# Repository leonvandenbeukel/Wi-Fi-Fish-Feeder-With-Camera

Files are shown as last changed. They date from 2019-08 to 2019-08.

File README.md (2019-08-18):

# Wi-Fi Fish Feeder With Camera

### Components

You need the following components:

* An ESP32-Cam module with Wi-Fi Antenna
* A large continuous rotating servo (it might also work with the more popular tiny MG90 but then you would have to modify it for continuous rotation and design another servo mount)
* Micro usb pcb
* 5V power adapter
* A regular 608 bearing 
* M3 nuts, bolts and washers
* 15 * 15 mm aluminium rod (optional)
* Wires

### 3D Printing

Use these settings: 0.2 / 10% infill. Support is needed for some pieces.

### Schema

Connect 5V, GND and GPIO12 for the signal wire to the servo. Use a micro usb pcb to connect it to a regular 5V power adapter.

### Arduino source

First install the ESP32 library. 
1. Start the Arduino IDE
2. Go to File > Preferences
3. Edit the "Additional Board Manager URLs" and add this URL:
    https://dl.espressif.com/dl/package_esp32_index.json
4. Go to Tools > Board > Boards Manager
5. Search for ESP32 and Install

Use an FTDI board and connect RX of the FTDI board to TX of the ESP32 board, TX (FTDI) to RX (ESP32) together with GND and 3.3V. If you're having trouble with the ESP32 (horizontal lines on the camera or "brownout detected" errors, you can try connecting an external 5V power supply to the 5V pin of the ESP32 (and connect GND's).  

Open the "WiFi-Fish-Feeder-With-Camera.ino" file from this repository and change the following setttings:

* Tools > Board, select ESP32 Wrover Module
* Tools > Port, select the COM port 
* In Tools > Partition Scheme, select "Huge APP (3MB No OTA)"

To upload the code, connect GPIO0 to GND and press the reset button on the device. Then hit upload in the Arduino IDE. After succesfully uploading press the reset button again and check the serial monitor to find out which IP Address it get's assigned. Browse to that IP and check if everything works.

### YouTube video

<a href="https://youtu.be/dWhmNZHbLFU" target="_blank">Click to view: Fish Feeder</a>

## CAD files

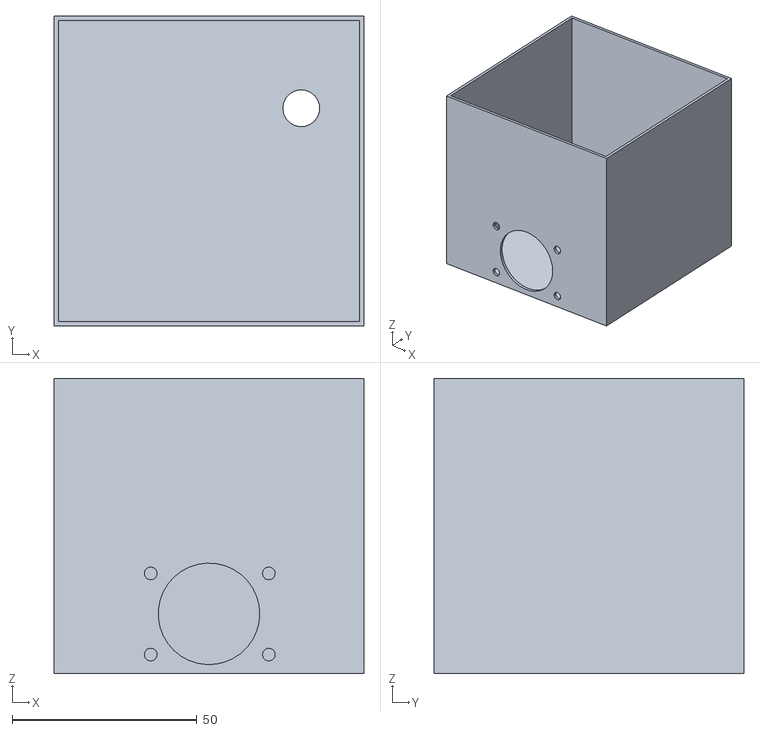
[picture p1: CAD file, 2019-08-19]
STL/Box.stl
84.0 x 84.0 x 80.0

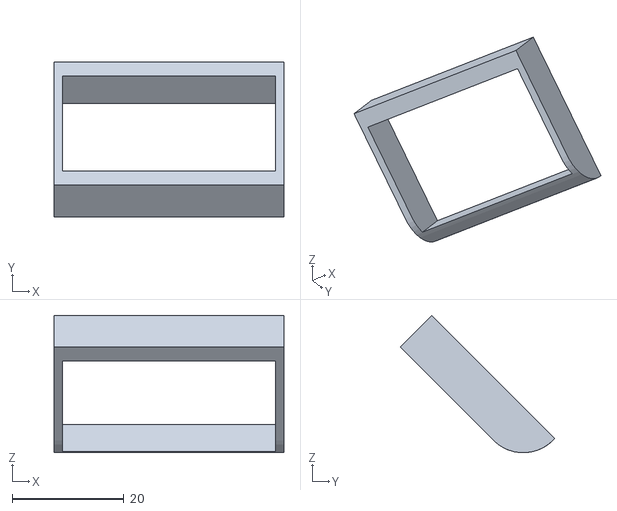
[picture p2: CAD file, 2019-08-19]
STL/Camera standoff.stl
41.1 x 27.6 x 24.5

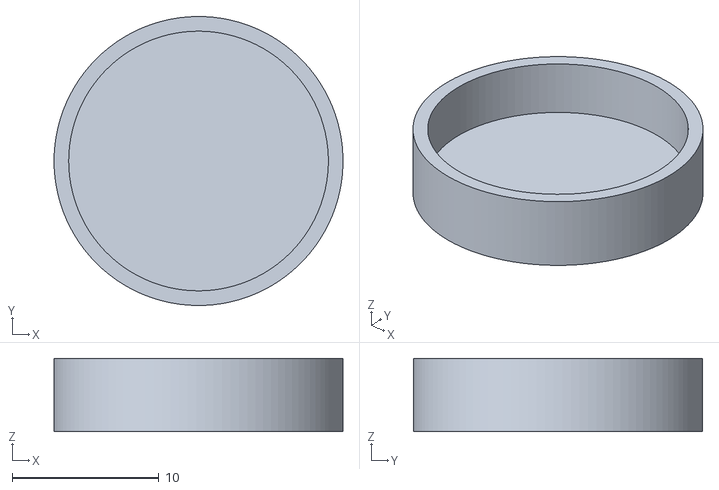
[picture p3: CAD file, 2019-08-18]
STL/Cap to close it off.stl
19.7 x 19.7 x 5.00

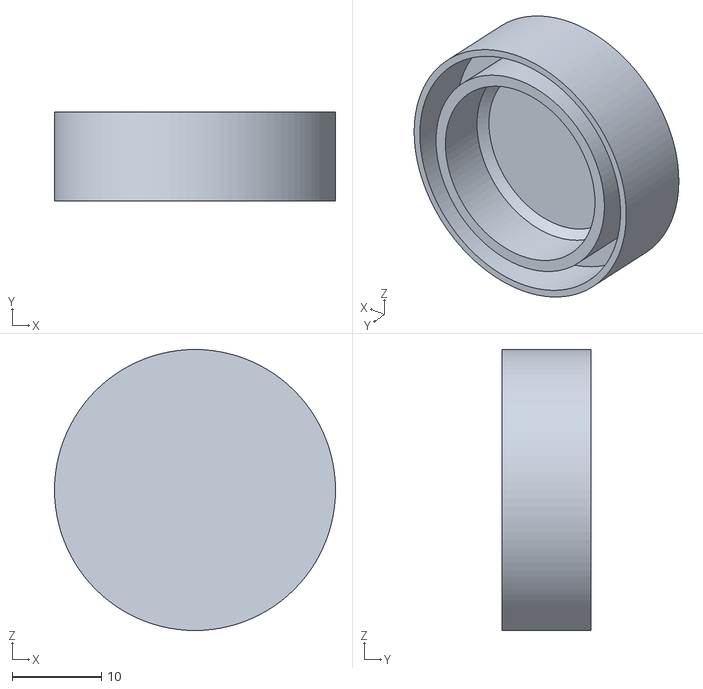
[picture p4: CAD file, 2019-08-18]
STL/Bearing Cap.stl
31.5 x 10.0 x 31.5

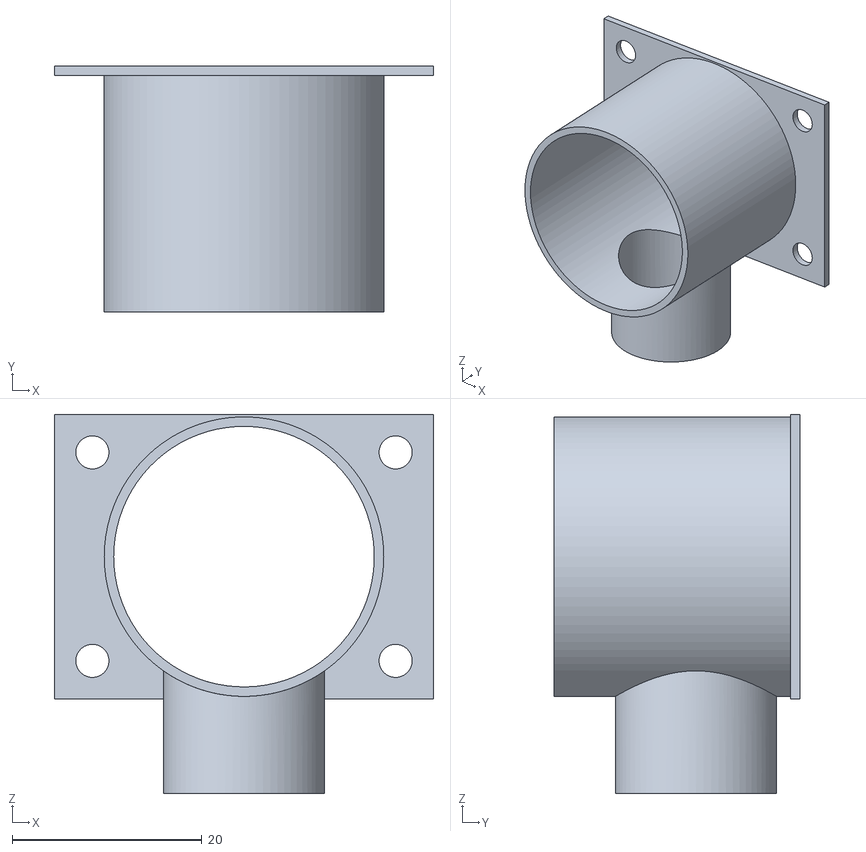
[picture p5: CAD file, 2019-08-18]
STL/Outlet.stl
40.0 x 26.0 x 40.0

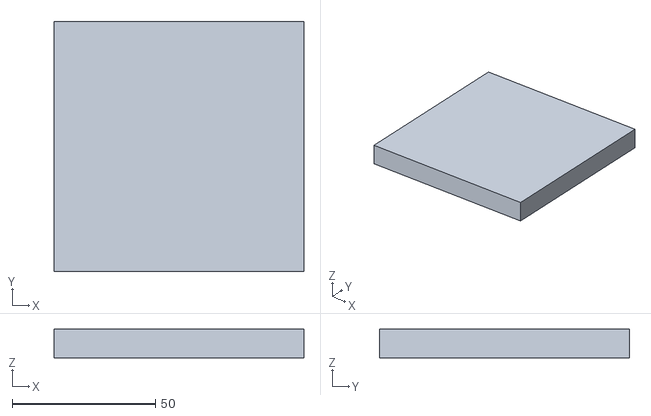
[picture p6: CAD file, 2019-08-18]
STL/Box lid.stl
87.2 x 87.2 x 10.0

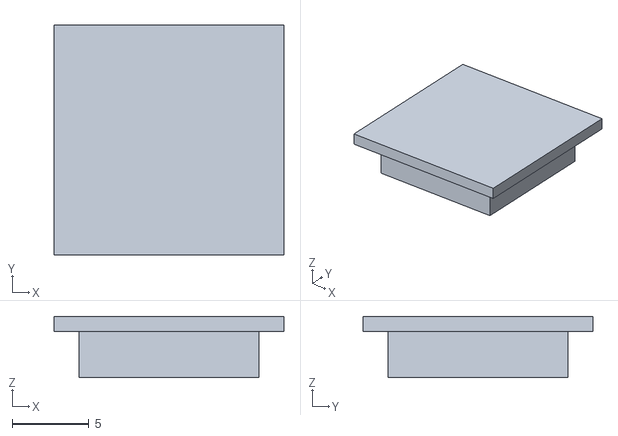
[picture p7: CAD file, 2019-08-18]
STL/End Cap.stl
15.0 x 15.0 x 4.00

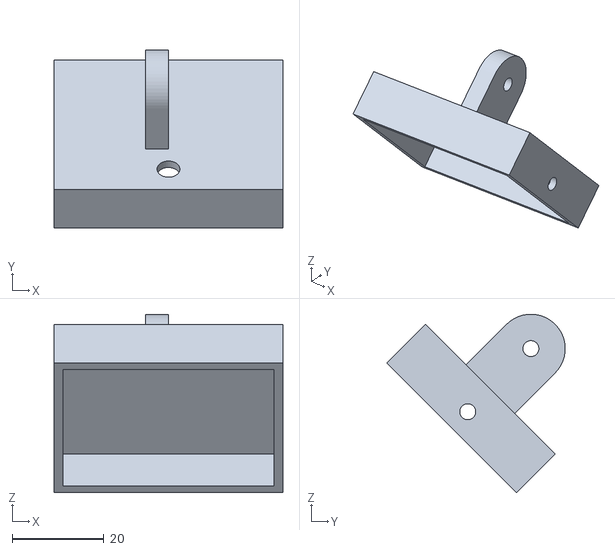
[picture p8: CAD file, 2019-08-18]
STL/Camera back tilt.stl
50.0 x 39.0 x 39.0

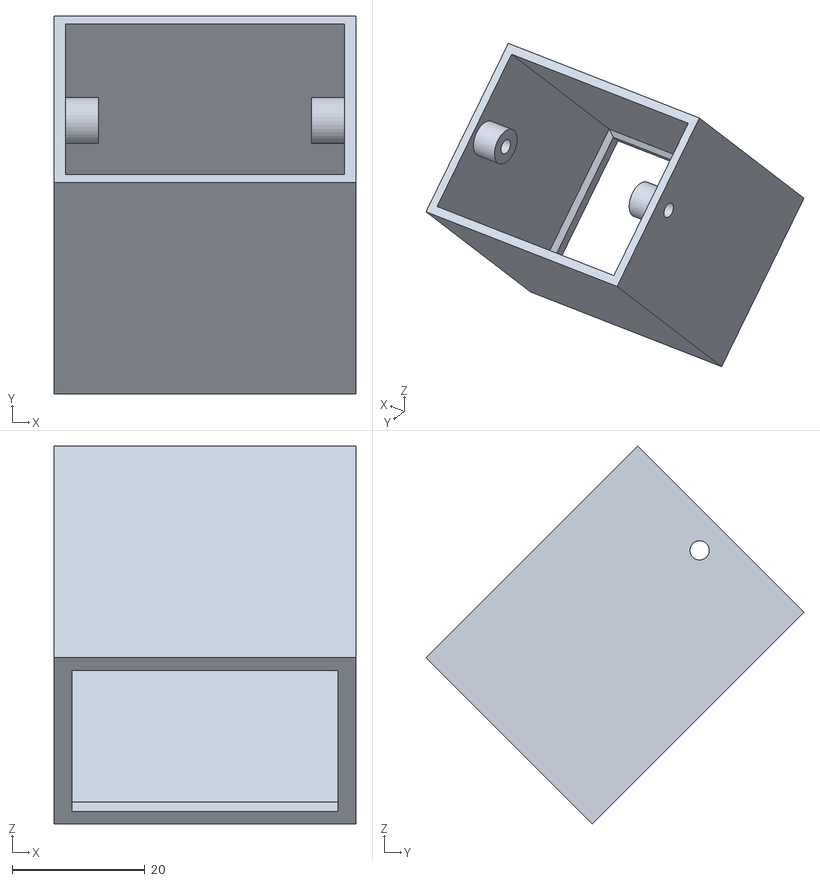
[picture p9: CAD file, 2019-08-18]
STL/Camera body.stl
45.4 x 56.9 x 56.9

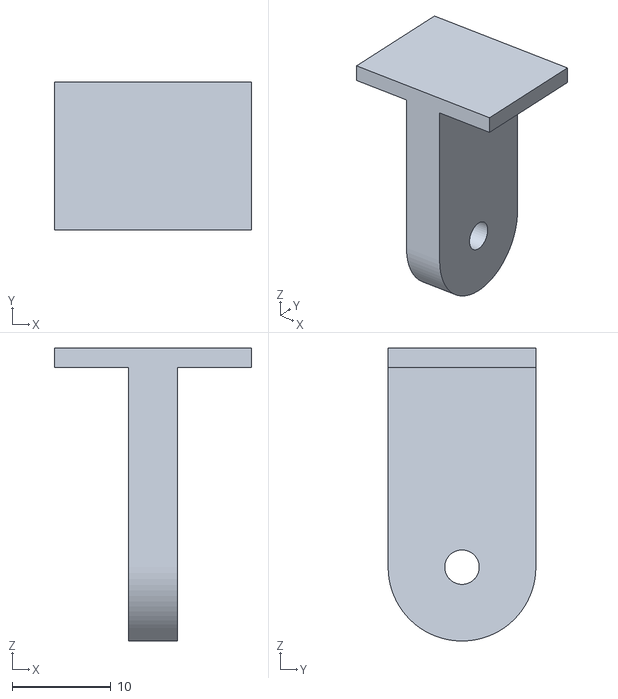
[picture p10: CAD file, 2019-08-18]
STL/Camera joint.stl
20.0 x 15.0 x 29.7

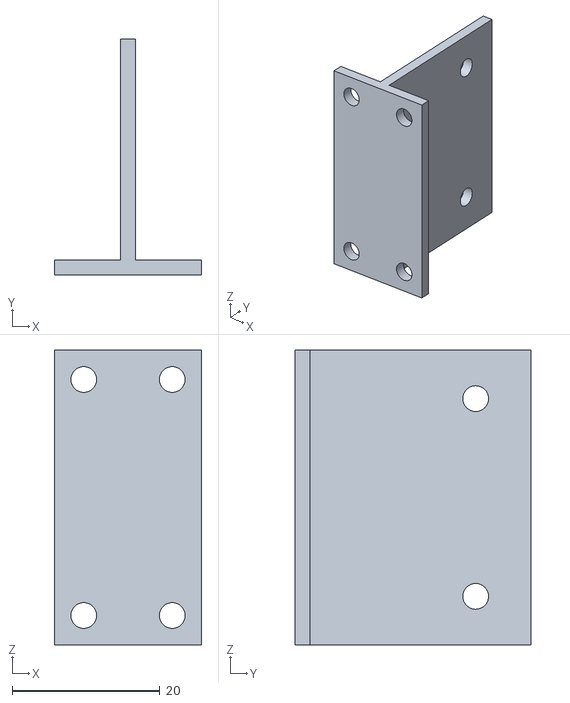
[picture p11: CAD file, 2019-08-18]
STL/Connection.stl
20.0 x 32.0 x 40.0

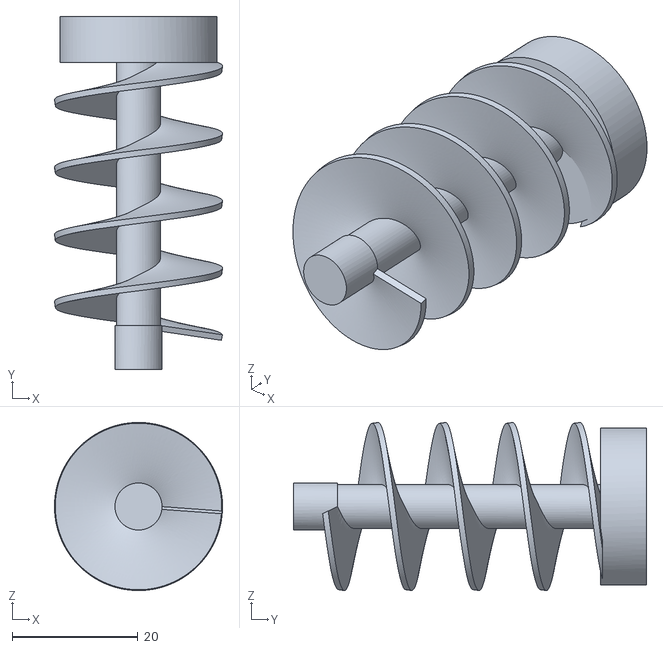
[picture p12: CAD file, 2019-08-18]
STL/Auger.stl
26.8 x 56.2 x 26.8

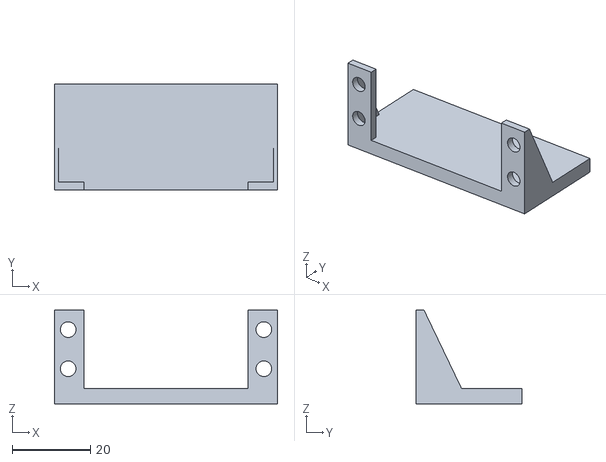
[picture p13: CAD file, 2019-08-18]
STL/Servo Mount.stl
57.0 x 27.0 x 24.0

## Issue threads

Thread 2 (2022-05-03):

Missing files

rlxd, 2022-05-03:
Arduino:1.8.20 Hourly Build 2022/04/25 09:33 (Windows 10), Board:"ESP32 Wrover Module, Huge APP (3MB No OTA/1MB SPIFFS), QIO, 40MHz, 115200, None"

Meerdere bibliotheken gevonden voor "WiFi.h"

app_httpd.cpp:36:20: fatal error: dl_lib.h: No such file or directory

Gebruikt: C:\Users\roy19\AppData\Local\Arduino15\packages\esp32\hardware\esp32\1.0.6\libraries\WiFi

compilation terminated.

Niet gebruikt: C:\Users\roy19\Desktop\arduino-nightly\libraries\WiFi

exit status 1

dl_lib.h: No such file or directory

Dit rapport zou meer informatie bevatten met
"Uitgebreide uitvoer weergeven tijden compilatie"
optie aan in Bestand -> Voorkeuren.

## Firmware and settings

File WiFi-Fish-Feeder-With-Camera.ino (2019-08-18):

#include "esp_camera.h"
#include <WiFi.h>

// Board: ESP32 Wrover
// Partition scheme: Huge APP

// Select camera model
//#define CAMERA_MODEL_WROVER_KIT
//#define CAMERA_MODEL_ESP_EYE
//#define CAMERA_MODEL_M5STACK_PSRAM
//#define CAMERA_MODEL_M5STACK_WIDE
#define CAMERA_MODEL_AI_THINKER

#include "camera_pins.h"

const char* ssid = "*** your ssid here ***";
const char* password = "*** your wi-fi password here ***";

void startCameraServer();
void checkFeederTimer();

void setup() {
  
  Serial.begin(115200);
  Serial.setDebugOutput(true);
  Serial.println();

  camera_config_t config;
  config.ledc_channel = LEDC_CHANNEL_0;
  config.ledc_timer = LEDC_TIMER_0;
  config.pin_d0 = Y2_GPIO_NUM;
  config.pin_d1 = Y3_GPIO_NUM;
  config.pin_d2 = Y4_GPIO_NUM;
  config.pin_d3 = Y5_GPIO_NUM;
  config.pin_d4 = Y6_GPIO_NUM;
  config.pin_d5 = Y7_GPIO_NUM;
  config.pin_d6 = Y8_GPIO_NUM;
  config.pin_d7 = Y9_GPIO_NUM;
  config.pin_xclk = XCLK_GPIO_NUM;
  config.pin_pclk = PCLK_GPIO_NUM;
  config.pin_vsync = VSYNC_GPIO_NUM;
  config.pin_href = HREF_GPIO_NUM;
  config.pin_sscb_sda = SIOD_GPIO_NUM;
  config.pin_sscb_scl = SIOC_GPIO_NUM;
  config.pin_pwdn = PWDN_GPIO_NUM;
  config.pin_reset = RESET_GPIO_NUM;
  config.xclk_freq_hz = 20000000;
  config.pixel_format = PIXFORMAT_JPEG;
  //init with high specs to pre-allocate larger buffers
  if(psramFound()){
    config.frame_size = FRAMESIZE_UXGA;
    config.jpeg_quality = 10;
    config.fb_count = 2;
  } else {
    config.frame_size = FRAMESIZE_SVGA;
    config.jpeg_quality = 12;
    config.fb_count = 1;
  }

#if defined(CAMERA_MODEL_ESP_EYE)
  pinMode(13, INPUT_PULLUP);
  pinMode(14, INPUT_PULLUP);
#endif

  // camera init
  esp_err_t err = esp_camera_init(&config);
  if (err != ESP_OK) {
    Serial.printf("Camera init failed with error 0x%x", err);
    return;
  }

  sensor_t * s = esp_camera_sensor_get();
  //initial sensors are flipped vertically and colors are a bit saturated
  if (s->id.PID == OV3660_PID) {
    s->set_vflip(s, 1);//flip it back
    s->set_brightness(s, 1);//up the blightness just a bit
    s->set_saturation(s, -2);//lower the saturation
  }
  //drop down frame size for higher initial frame rate
  s->set_framesize(s, FRAMESIZE_QVGA);

#if defined(CAMERA_MODEL_M5STACK_WIDE)
  s->set_vflip(s, 1);
  s->set_hmirror(s, 1);
#endif

  pinMode(4, OUTPUT);

  WiFi.begin(ssid, password);

  while (WiFi.status() != WL_CONNECTED) {
    delay(500);
    Serial.print(".");
  }
  Serial.println("");
  Serial.println("WiFi connected");

  startCameraServer();

  Serial.print("Camera Ready! Use 'http://");
  Serial.print(WiFi.localIP());
  Serial.println("' to connect");
}

void loop() {

   checkFeederTimer();
   delay(10);

}

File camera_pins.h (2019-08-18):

  
#if defined(CAMERA_MODEL_WROVER_KIT)
#define PWDN_GPIO_NUM    -1
#define RESET_GPIO_NUM   -1
#define XCLK_GPIO_NUM    21
#define SIOD_GPIO_NUM    26
#define SIOC_GPIO_NUM    27

#define Y9_GPIO_NUM      35
#define Y8_GPIO_NUM      34
#define Y7_GPIO_NUM      39
#define Y6_GPIO_NUM      36
#define Y5_GPIO_NUM      19
#define Y4_GPIO_NUM      18
#define Y3_GPIO_NUM       5
#define Y2_GPIO_NUM       4
#define VSYNC_GPIO_NUM   25
#define HREF_GPIO_NUM    23
#define PCLK_GPIO_NUM    22

#elif defined(CAMERA_MODEL_ESP_EYE)
#define PWDN_GPIO_NUM    -1
#define RESET_GPIO_NUM   -1
#define XCLK_GPIO_NUM    4
#define SIOD_GPIO_NUM    18
#define SIOC_GPIO_NUM    23

#define Y9_GPIO_NUM      36
#define Y8_GPIO_NUM      37
#define Y7_GPIO_NUM      38
#define Y6_GPIO_NUM      39
#define Y5_GPIO_NUM      35
#define Y4_GPIO_NUM      14
#define Y3_GPIO_NUM      13
#define Y2_GPIO_NUM      34
#define VSYNC_GPIO_NUM   5
#define HREF_GPIO_NUM    27
#define PCLK_GPIO_NUM    25

#elif defined(CAMERA_MODEL_M5STACK_PSRAM)
#define PWDN_GPIO_NUM     -1
#define RESET_GPIO_NUM    15
#define XCLK_GPIO_NUM     27
#define SIOD_GPIO_NUM     25
#define SIOC_GPIO_NUM     23

#define Y9_GPIO_NUM       19
#define Y8_GPIO_NUM       36
#define Y7_GPIO_NUM       18
#define Y6_GPIO_NUM       39
#define Y5_GPIO_NUM        5
#define Y4_GPIO_NUM       34
#define Y3_GPIO_NUM       35
#define Y2_GPIO_NUM       32
#define VSYNC_GPIO_NUM    22
#define HREF_GPIO_NUM     26
#define PCLK_GPIO_NUM     21

#elif defined(CAMERA_MODEL_M5STACK_WIDE)
#define PWDN_GPIO_NUM     -1
#define RESET_GPIO_NUM    15
#define XCLK_GPIO_NUM     27
#define SIOD_GPIO_NUM     22
#define SIOC_GPIO_NUM     23

#define Y9_GPIO_NUM       19
#define Y8_GPIO_NUM       36
#define Y7_GPIO_NUM       18
#define Y6_GPIO_NUM       39
#define Y5_GPIO_NUM        5
#define Y4_GPIO_NUM       34
#define Y3_GPIO_NUM       35
#define Y2_GPIO_NUM       32
#define VSYNC_GPIO_NUM    25
#define HREF_GPIO_NUM     26
#define PCLK_GPIO_NUM     21

#elif defined(CAMERA_MODEL_AI_THINKER)
#define PWDN_GPIO_NUM     32
#define RESET_GPIO_NUM    -1
#define XCLK_GPIO_NUM      0
#define SIOD_GPIO_NUM     26
#define SIOC_GPIO_NUM     27

#define Y9_GPIO_NUM       35
#define Y8_GPIO_NUM       34
#define Y7_GPIO_NUM       39
#define Y6_GPIO_NUM       36
#define Y5_GPIO_NUM       21
#define Y4_GPIO_NUM       19
#define Y3_GPIO_NUM       18
#define Y2_GPIO_NUM        5
#define VSYNC_GPIO_NUM    25
#define HREF_GPIO_NUM     23
#define PCLK_GPIO_NUM     22

#else
#error "Camera model not selected"
#endif
